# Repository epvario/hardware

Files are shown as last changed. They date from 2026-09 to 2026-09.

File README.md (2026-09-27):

## EPVario Hardware ( work-in-progress )

This Repository holds PCB Design files, orderable production files, Case files and information around anything Hardware related.

### Case:
The CAD Design for Case, Backplates and Buttons etc. is available for free on Onshape.com
https://cad.onshape.com/documents/7c7b5a47965e5aa4a5c3c6fc/w/4d91674f4ec0d4e9e5bb48e4/e/9528d9da3515a60f70c45c22

Feel free to create a copy and modify based on your needs

### Mainboard:
The repository contains files of the 4-Layer PCB and the components, compatible to order at JLCPCB for example (a batch of 10 or more)

### Components:
Most components can be sourced on Ali Express or even Amazon.
Here is a sample of Product links:
- Display, WeAct 2.9" black/White
  - [aliexpress.com/item/1005004644515880.html](https://aliexpress.com/item/1005004644515880.html)
- Display connector
  - [aliexpress.com/item/1005004740833501.html](https://aliexpress.com/item/1005004740833501.html)
- GPS, Caddx Walksnail WS-M181
  - i.e. [aliexpress.com/item/1005012485670261.html](https://aliexpress.com/item/1005012485670261.html)
  - or any other shop
- Battery, EEMB 603449 1100mAh Lipo
  - [amazon.de/dp/B08VRYS8FT](www.amazon.de/dp/B08VRYS8FT)
- Battery connector, SMT PH2.0-2P JST
  - [aliexpress.com/item/1005001350048662.html](https://aliexpress.com/item/1005001350048662.html)
- Speaker, 2809 8 Ohm, 1W
  - [aliexpress.com/item/1005012134376029.html](https://aliexpress.com/item/1005012134376029.html)
- FANET Module (optional), Radiomaster XR1
  - [aliexpress.com/item/1005009297350467.html](https://aliexpress.com/item/1005009297350467.html)
- FANET Antenna
  - to be defined
- Screws, M2 16mm, 
  - preferrable stainless steele, less magnetic
  - i.e. [ebay.de/itm/401642079555](www.ebay.de/itm/401642079555)
- Micro SD Card, max 32GB, preferrably SanDisk

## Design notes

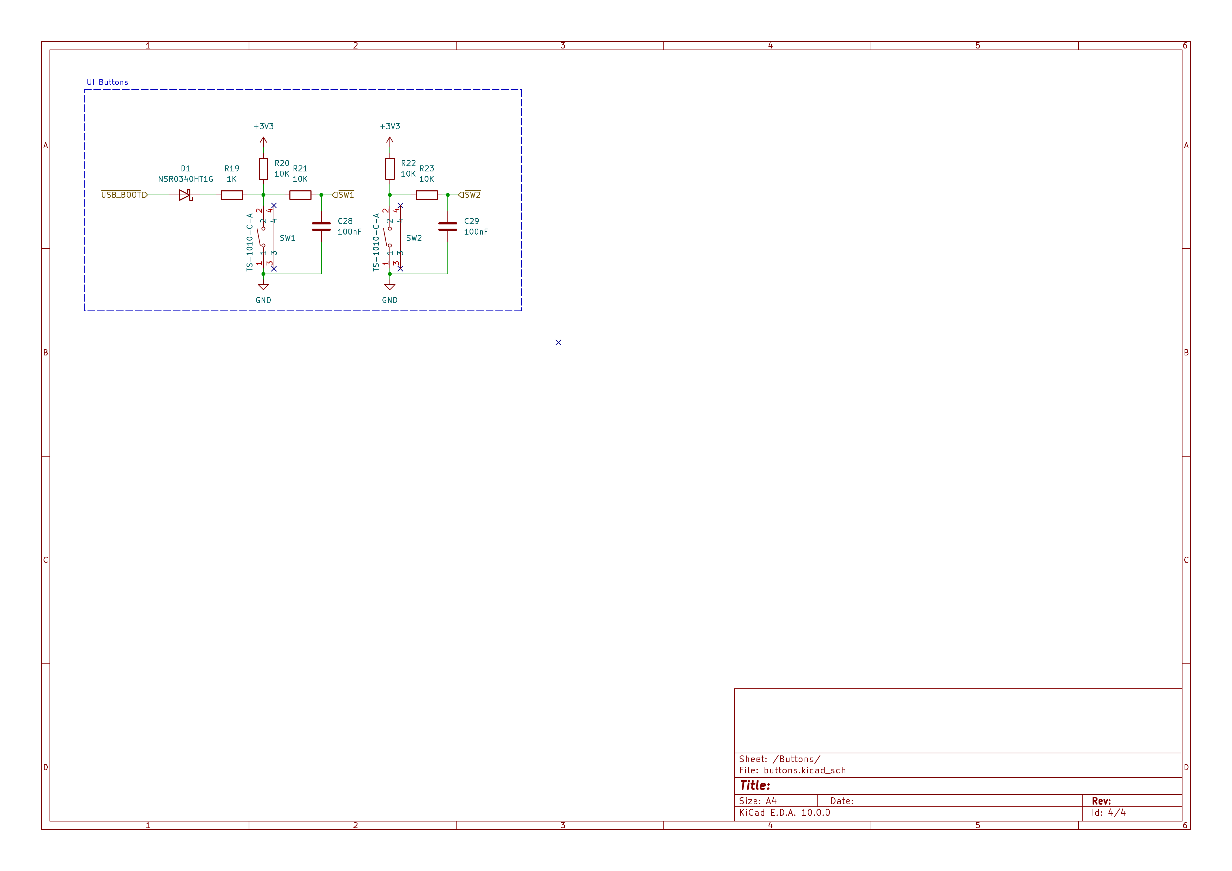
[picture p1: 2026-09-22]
rev3/schematics/epvario_rev3_buttons.png

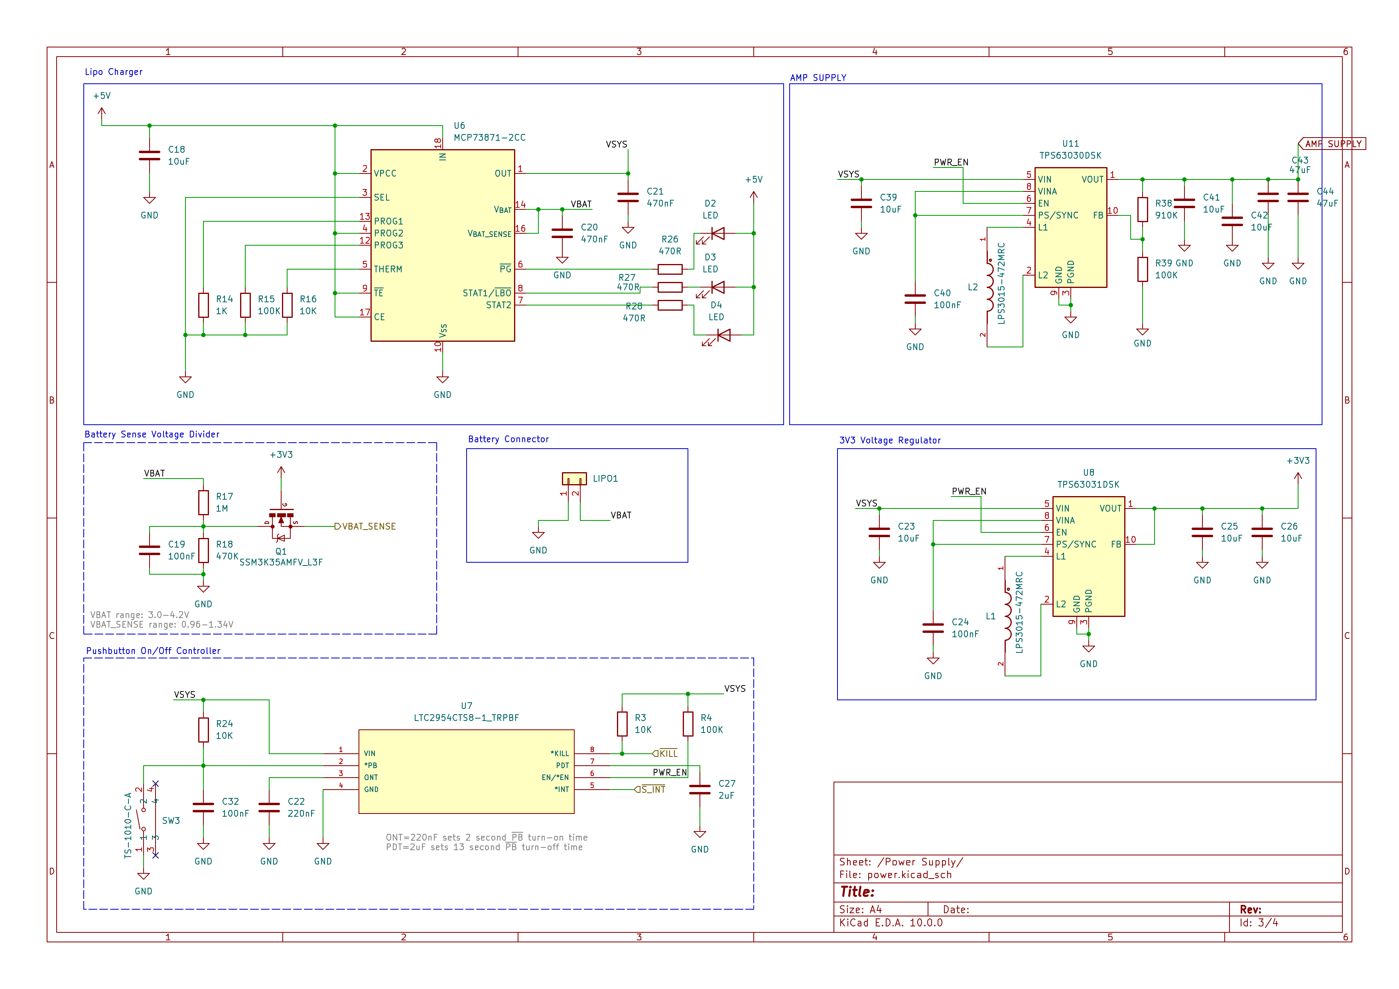
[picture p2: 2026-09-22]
rev3/schematics/epvario_rev3_power_supply.png

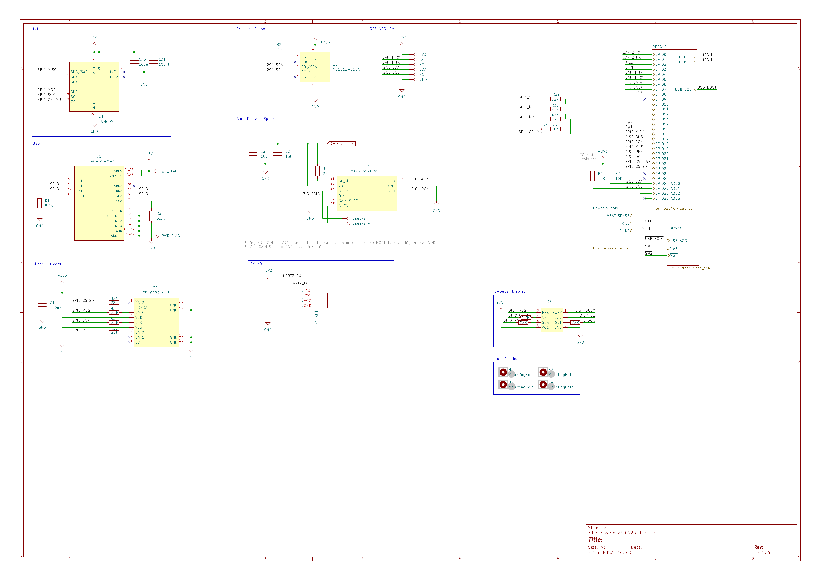
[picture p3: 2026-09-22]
rev3/schematics/epvario_rev3.png

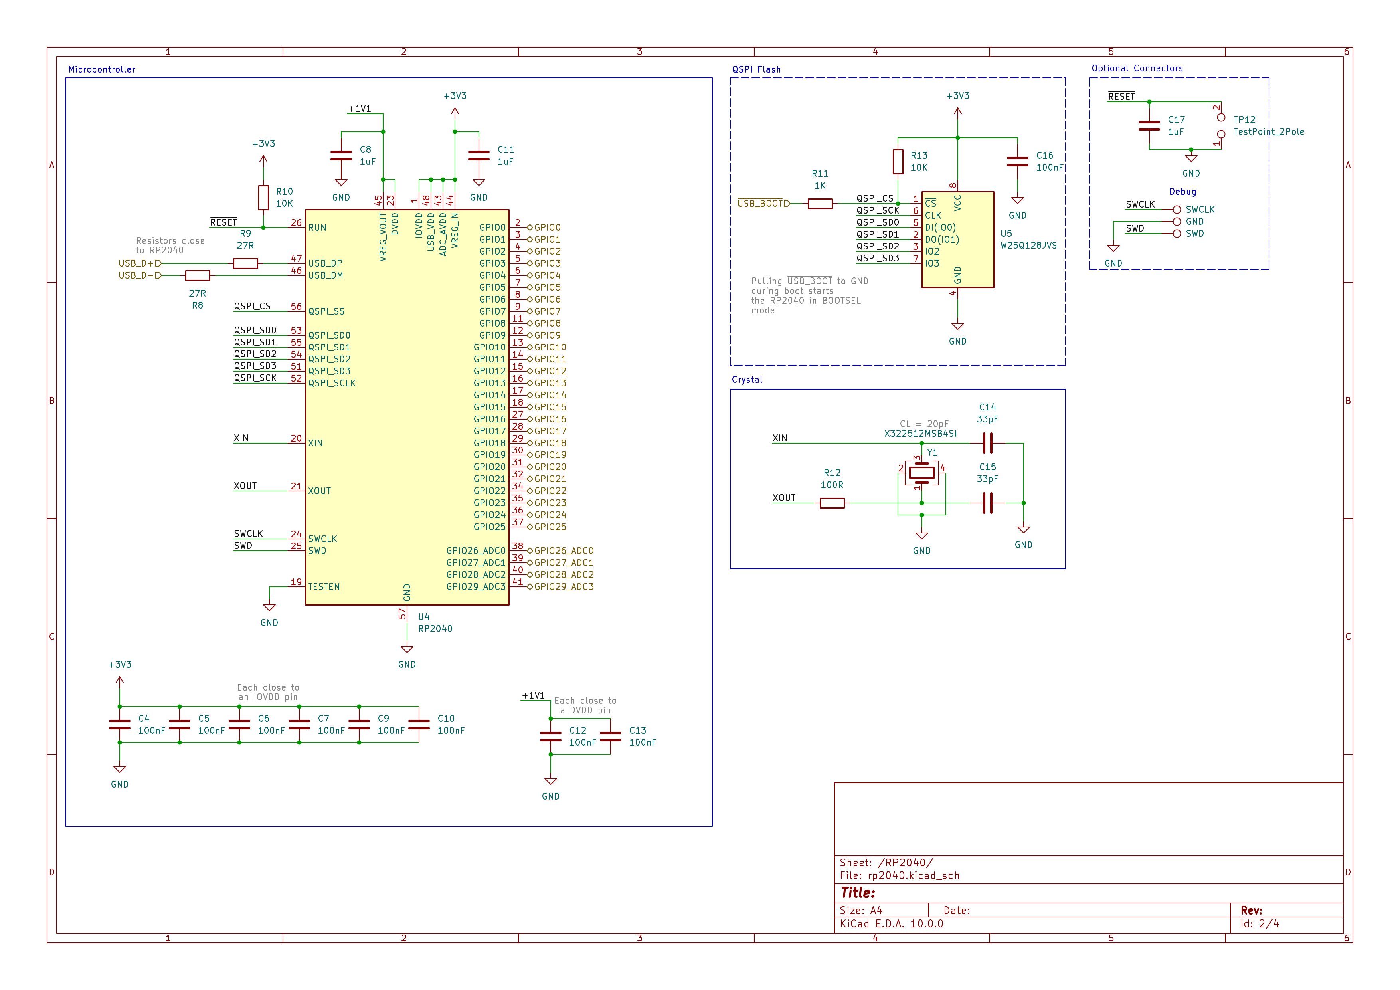
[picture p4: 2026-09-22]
rev3/schematics/epvario_rev3_RP2040.png

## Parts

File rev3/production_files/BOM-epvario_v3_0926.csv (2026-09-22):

Comment | Designator | Footprint | LCSC | Quantity
100K | R15,R39,R4 | R_0402_1005Metric | C25741 | 3
100R | R12 | R_0402_1005Metric | C25076 | 1
100nF | C1,C10,C12,C13,C16,C19,C24,C28,C29,C30,C31,C32,C4,C40,C5,C6,C7,C9 | C_0402_1005Metric | C1525 | 18
10K | R10,R13,R16,R20,R21,R22,R23,R24,R3,R32,R6,R7 | R_0402_1005Metric | C25744 | 12
10uF | C18,C2,C23,C25,C26,C39,C41,C42 | C_0402_1005Metric | C15525 | 8
1K | R11,R14,R19,R25 | R_0402_1005Metric | C11702 | 4
1M | R17 | R_0402_1005Metric | C26083 | 1
1uF | C11,C3,C8 | C_0402_1005Metric | C52923 | 3
220nF | C22 | C_0402_1005Metric | C16772 | 1
22R | R29,R30,R31,R33,R34,R35,R36,R37,R40,R41 | R_0402_1005Metric | C25092 | 10
27R | R8,R9 | R_0402_1005Metric | C25100 | 2
2K | R5 | R_0402_1005Metric | C4109 | 1
2uF | C27 | C_0402_1005Metric | C12530 | 1
33pF | C14,C15 | C_0402_1005Metric | C1562 | 2
470K | R18 | R_0402_1005Metric | C23178 | 1
470R | R27 | R_0402_1005Metric | C25117 | 1
470nF | C20,C21 | C_0402_1005Metric | C23733 | 2
47uF | C43,C44 | C_0805_2012Metric | C16780 | 2
5.1K | R1,R2 | R_0402_1005Metric | C25905 | 2
910K | R38 | R_0402_1005Metric | C11866 | 1
LPS3015-472MRC | L1,L2 | IND_LPS3015-472MRC | C17300975 | 2
LSM6DS3 | U1 | LGA-14_3x2.5mm_P0.5mm_LayoutBorder3x4y | C967633 | 1
LTC2954CTS8-1_TRPBF | U7 | TSOT-23_TS8 | C683782 | 1
MAX98357AEWL+T | U3 | WLP-9_L1.4-W1.3-P0.40-R3-C3-BR | C2682619 | 1
MCP73871-2CC | U6 | QFN-20-1EP_4x4mm_P0.5mm_EP2.5x2.5mm | C511310 | 1
MS5611-01BA | U9 | LGA-8_3x5mm_P1.25mm | C15639 | 1
NSR0340HT1G | D1 | D_SOD-323 | C90392 | 1
RP2040 | U4 | QFN-56-1EP_7x7mm_P0.4mm_EP3.2x3.2mm | C2040 | 1
SSM3K35AMFV_L3F | Q1 | VESM_SOT-723_ | C150155 | 1
TF-CARD H1.8 | TF1 | TF-SMD_TF-CARD-H1.8 | C7529389 | 1
TPS63030DSK | U11 | WSON-10-1EP_2.5x2.5mm_P0.5mm_EP1.2x2mm | C469840 | 1
TPS63031DSK | U8 | WSON-10-1EP_2.5x2.5mm_P0.5mm_EP1.2x2mm | C15516 | 1
TS-1010-C-A | SW1,SW2,SW3 | KEY-SMD_TX-1010-X-X | C692458 | 3
TYPE-C-31-M-12 | J1 | HRO_TYPE-C-31-M-12 | C165948 | 1
W25Q128JVS | U5 | SOIC-8_5.23x5.23mm_P1.27mm | C97521 | 1
X322512MSB4SI | Y1 | Crystal_SMD_3225-4Pin_3.2x2.5mm | C9002 | 1
SCL | TP7 | TestPoint_Pad_D2.0mm |  | 1
TX | TP4 | TestPoint_Pad_D2.0mm |  | 1
3V3 | TP3 | TestPoint_Pad_D2.0mm |  | 1
SDA | TP6 | TestPoint_Pad_D2.0mm |  | 1
RX | TP5 | TestPoint_Pad_D2.0mm |  | 1
~ | DS1 | epv_2809_v2 |  | 1
RM_XR1 | U2 | RM_XR1 |  | 1
LED | D3 | LED_0805_2012Metric_Pad1.15x1.40mm_HandSolder |  | 1
~ | LIPO1 | JST_PH_S2B-PH-SM4-TB_1x02-1MP_P2.00mm_Horizontal |  | 1
SWCLK | TP9 | TestPoint_Pad_D2.0mm |  | 1
GND | TP8 | TestPoint_Pad_D2.0mm |  | 1
SWD | TP11 | TestPoint_Pad_D2.0mm |  | 1
Speaker- | TP2 | TestPoint_Pad_D2.0mm |  | 1
GND | TP10 | TestPoint_Pad_D2.0mm |  | 1
Speaker+ | TP1 | TestPoint_Pad_D2.0mm |  | 1

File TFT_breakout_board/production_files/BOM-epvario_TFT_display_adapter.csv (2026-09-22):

Comment | Designator | Footprint | LCSC | Quantity
~ | DS2 | HRS_FH34SRJ-24S-0.5SH_50_ | C324726 | 1
~ | DS1 | 2.9_breakout |  | 1
2.2uF | C2 | C_0805_2012Metric_Pad1.18x1.45mm_HandSolder |  | 1
2.2uF | C5 | C_0805_2012Metric_Pad1.18x1.45mm_HandSolder |  | 1
0.1uF | C1 | C_0805_2012Metric_Pad1.18x1.45mm_HandSolder |  | 1
0.1uF | C4 | C_0805_2012Metric_Pad1.18x1.45mm_HandSolder |  | 1
0.1uF | C3 | C_0805_2012Metric_Pad1.18x1.45mm_HandSolder |  | 1
2.2uF | C6 | C_0805_2012Metric_Pad1.18x1.45mm_HandSolder |  | 1

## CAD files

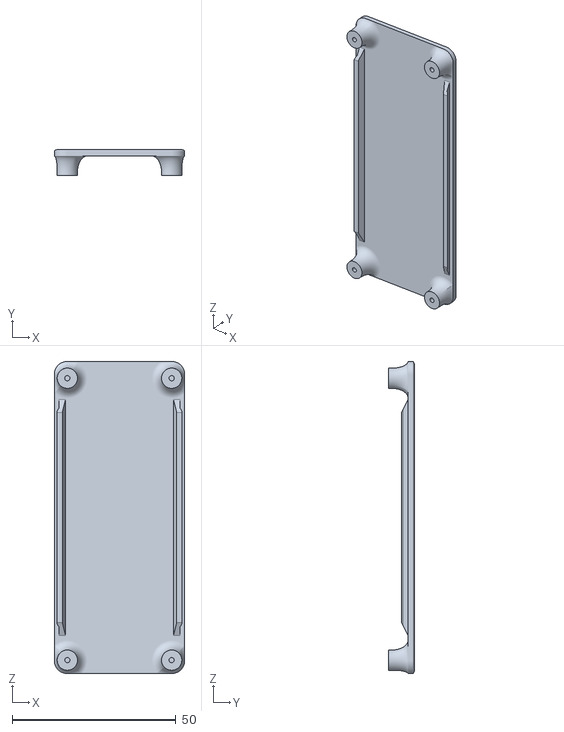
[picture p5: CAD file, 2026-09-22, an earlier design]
rev2/case/epvario_rev2_v18.6_2mm_iph5 - backplate_v2_clean.stl
39.9 x 8.00 x 95.4

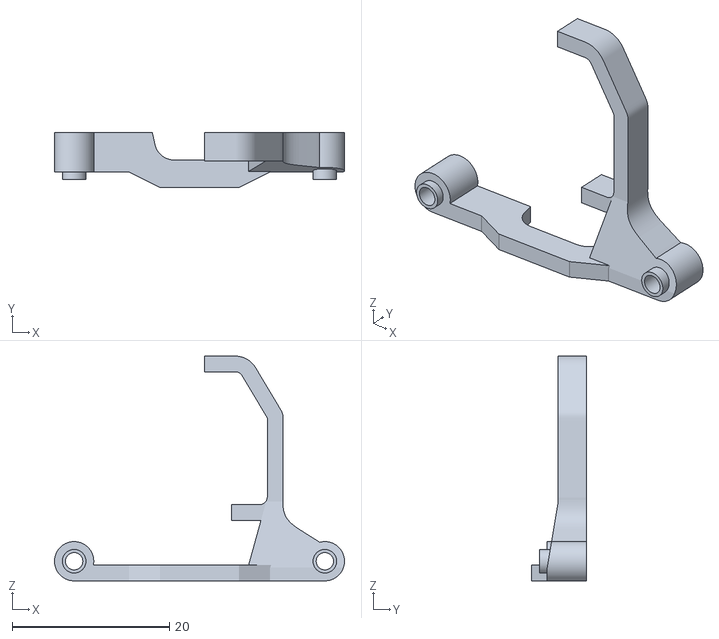
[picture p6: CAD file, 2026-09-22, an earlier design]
rev2/case/epvario_rev2_v18.7_2mm_iph5 - distance_helper_bottom.stl
36.9 x 7.00 x 28.6

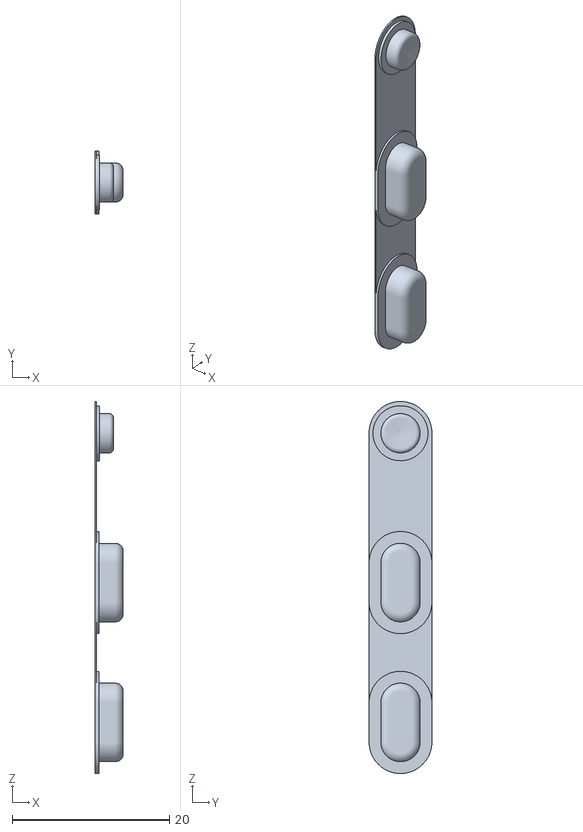
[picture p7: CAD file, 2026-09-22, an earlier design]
rev2/case/epvario_rev2_v18.6_2mm_iph5 - buttons.stl
3.60 x 8.00 x 47.3

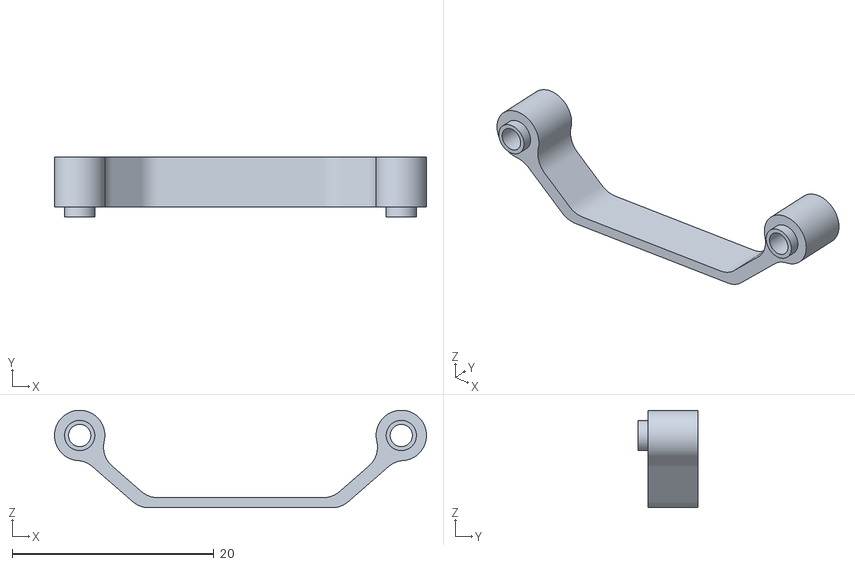
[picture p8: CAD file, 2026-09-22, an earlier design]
rev2/case/epvario_rev2_v18.6_2mm_iph5 - distance_helper_top.stl
36.9 x 6.00 x 9.67

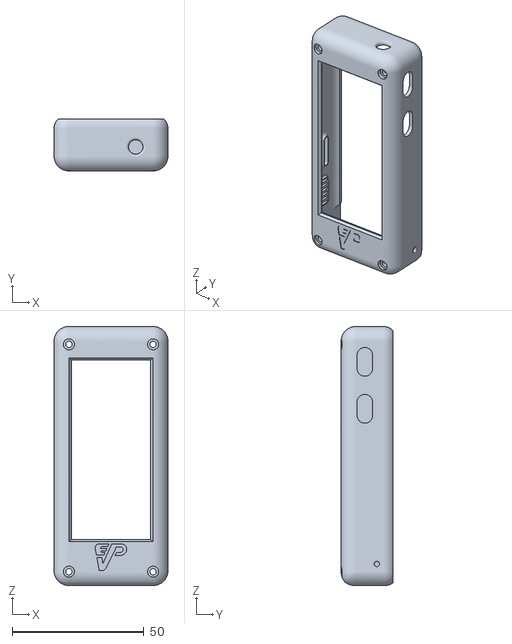
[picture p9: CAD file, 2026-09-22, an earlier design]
rev2/case/epvario_rev2_v18.6_2mm_iph5 - case.stl
43.2 x 19.6 x 98.2

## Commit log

2026-09-22 adding production final files of rev3
    - corrected RX/TX on XR1 UART
    - fixed PowerButton Resistor/Capacity
    - moved USB-C to the side
    - shorten PCB by 7mm to fit 2809 speaker
    - add JSTPH2 battery connector pad
    - add R36 on SPI SD
    - R35 closer to MISO SD card
    - add separate resistors for MOSI and SCK for SPI SD and Display
    - CS_SD: add a resistor (near the RP2040)
    - CS_LCD: near the RP2040
    - optimized TF1 and DS1 SPI trace length
    - improved PowerButton tracing
    - relocated AMP, shortend OUT traces
    [BOM-epvario_v3_0926.csv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]
2026-09-22 adding TFT breakout board for 2.9 reflecting TFT screens
    [BOM-epvario_TFT_display_adapter.csv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]
2026-09-22 added rev2 files
    [BOM-epvario_v2_XR1_SPI_i5spk.csv, epvario_rev2_v18.6_2mm_iph5 - backplate_v2_clean.stl, epvario_rev2_v18.6_2mm_iph5 - buttons.stl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]
2026-10-28 adding updated TFT breakout board and fuzzy skin 3mf project
2026-10-28 removing TFT breakout board which misses charge pump caps
